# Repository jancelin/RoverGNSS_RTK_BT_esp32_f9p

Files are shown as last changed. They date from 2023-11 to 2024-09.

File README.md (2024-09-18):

> experimental code!!!

### This code allows you to connect an esp32 coupled to a Ublox F9P GNSS module on the UART port to use NTRIP clients on smartphones such as:
* [Lefebure](https://play.google.com/store/apps/details?id=com.lefebure.ntripclient) 	:white_check_mark:
* [BTGNSS](https://play.google.com/store/apps/details?id=com.clearevo.bluetooth_gnss) 	:white_check_mark:
* [SwMpas](https://play.google.com/store/apps/details?id=np.com.softwel.swmaps) 	:white_check_mark:

## Param Arduino IDE

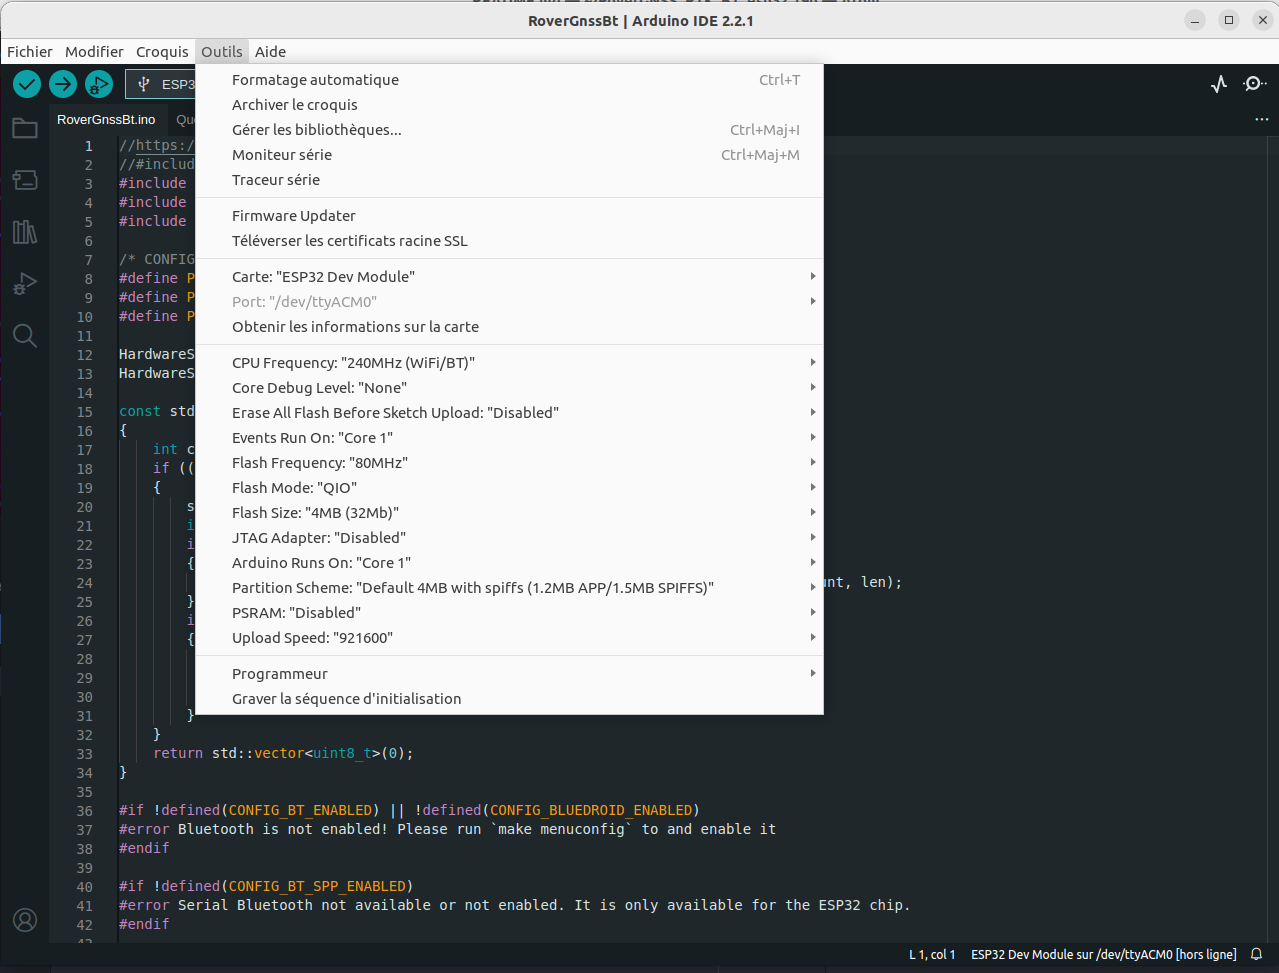
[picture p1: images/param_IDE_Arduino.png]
param


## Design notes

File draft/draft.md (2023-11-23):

# Cahier des charges - Développement et Fabrication Projet Rover GNSS

## Modules GNSS Possibles

1. **F9P Drotek Mpcie:**
   - [Lien Produit](https://store-drotek.com/923-DP0602.html)
   - [Fiche Technique](https://raw.githubusercontent.com/drotek/datasheets/master/DrotekDoc_0923%20-%20DP0602%20(mPCIe%20F9P).pdf)
   - 

2. **F9P Ardusimple Mpcie:**
   - [Lien Produit](https://www.ardusimple.com/product/simplertk2b-mpcie-zed-f9p/)
   - Connectique en évolution pour les prochains modèles, en attendant : [Guide d'intégration PCB](https://www-ardusimple-com.translate.goog/pcb-integration-guide-simplertk2b-mpcie/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)

3. **Mosaic X5 Ardusimple Mpcie:**
   - [Lien Produit](https://www.ardusimple.com/product/simplertk3b-mpcie-septentrio-mosaic/)
   - 

## Référence des Pinouts des Cartes GNSS en Mpcie

1. **F9P Mpcie Ardusimple:**
   - 36 USB_DATA-
   - 38 USB_DATA+
   - 22 RESET

2. **F9P Mpcie Drotek:**
   - 17 UART1 Tx
   - 19 UART1 Rx
   - 36 USB_DATA-
   - 38 USB_DATA+
   - 45 UART2 Tx
   - 47 UART2 Rx
   - 49 EXTINT
   - 51 TIMEPULSE

3. **Mosaic X5 Mpcie Ardusimple:**
   - 11 COM2 Rx
   - 13 COM2 Tx
   - 17 EXTINT
   - 19 TIMEPLUSE
   - 22 RESET
   - 36 USB_DATA-
   - 38 USB_DATA+
   - 45 COM3 Rx
   - 47 COM3 Tx
   - 49 COM1 Rx
   - 51 COM1 Tx

## Microcontrôleur ESP32 WROOM

- [Pinout Joy-It SBC-NodeMCU-ESP32](https://joy-it.net/files/files/Produkte/SBC-NodeMCU-ESP32/SBC-NodeMCU-ESP32-Manual-2021-06-29.pdf)

  

## Connexion ESP32 -> F9P Drotek

### Dev Actuel Transposé au Matériel Connectique Mpcie

> L'ensemble des projets est théoriquement adaptable en connexion sur les pinouts USB, mais l'accès aux autres pins est essentiel au maximum.

- **Projet "ROVER Bluetooth"** ([Lien GitHub](https://github.com/jancelin/RoverGNSS_RTK_BT_esp32_f9p))
  - 16 UART1 Rx ESP32 -> UART1 17 Tx Drotek F9P
  - 17 UART1 Tx ESP32 -> UART1 19 Rx Drotek F9P

- **Projet "PHYSALIA_MAVI"** ([Lien GitHub](https://github.com/jancelin/physalia/tree/main/buoy_mavi))
  - Connexion data en SDA/SDC, possible de l'adapter en UART (normalement):
  - 16 UART1 Rx ESP32 -> UART1 17 Tx Drotek F9P
  - 17 UART1 Tx ESP32 -> UART1 19 Rx Drotek F9P

- **F9p-ntrip-esp32** ([Lien GitHub](https://github.com/buched/F9p-ntrip-esp32))
  - 17 UART1 Rx ESP32 -> UART1 17 Tx Drotek F9P
  - 23 VSPI_MOSI ESP32 -> UART1 19 Rx Drotek F9P

...

## Possibilités

### Objectif PCB

Offrir le plus de possibilités de connexion entre l'ESP32, le récepteur GNSS, et des pins à souder. Si il n'est pas possible d'avoir une connexion directe, prévoir des pins à souder qui amènent directement au port du matériel.

### Pins Communs aux Récepteurs GNSS Mpcie

- **Pin 36**
  - USB_DATA- (Sortie - Drotek)
  - USB_DATA- (Sortie - Ardusimple MosaicX5)

- **Pin 38**
  - USB_DATA+ (Sortie - Drotek)
  - USB_DATA+ (Sortie - Ardusimple MosaicX5)

- **Pin 17**
  - Extint (Entrée et Sortie)
  - UART1 Tx (Sortie - Drotek)

- **Pin 19**
  - Timepulse (Entrée et Sortie)
  - UART1 Rx (Entrée - Drotek)
  - Timepulse (Sortie - Ardusimple MosaicX5)

- **Pin 45**
  - UART2 Tx (Sortie - Drotek)
  - COM3 Rx (Entrée - Ardusimple MosaicX5)

- **Pin 47**
  - UART2 Rx (Entrée - Drotek)
  - COM3 Tx (Sortie - Ardusimple MosaicX5)

- **Pin 49**
  - Extint (Sortie - Drotek)
  - COM1 Rx (Entrée - Ardusimple MosaicX5)

- **Pin 51**
  - Timepulse (Sortie - Drotek)
  - COM1 Tx (Sortie - Ardusimple MosaicX5)

### Connexion ESP32 -> GNSS

- **Pin 01 UART0 Tx** -> **Pin 36**
  - USB_DATA- (Entrée - Drotek)
  - USB_DATA- (Entrée - Ardusimple MosaicX5)

- **Pin 03 UART0 Rx** -> **Pin 38**
  - USB_DATA+ (Sortie - Drotek)
  - USB_DATA+ (Sortie - Ardusimple MosaicX5)

- **Pin 16 UART1 Tx** -> **Pin 45**
  - UART2 Tx (Sortie - Drotek)
  - COM3 Rx (Entrée - Ardusimple MosaicX5)

- **Pin 17 UART1 Rx** -> **Pin 47**
  - UART2 Rx (Entrée - Drotek)
  - COM3 Tx (Sortie - Ardusimple MosaicX5)
 
- **Pin 22 VSPI_MOSI Rx** -> 

### Objectifs Supplémentaires

- Rendre accessible ESP32 UART1-GNSS 45/47 + SCL/SDA en connectique à souder
- Rendre accessible alimentation 3.3V/VIN+GND en connectique à souder
- Switch pour paramétrage USB (UART0) vers ESP32 ou récepteur GNSS
- Microcontrôleur ESP32 WROOM pour Bluetooth classique
- Charge batterie connexion USB
- Batterie 2000mAh
- connecteur batterie standard 2mm
- Niveau de charge
- Interrupteur général ON/OFF
- Compact, plat, format carte de crédit
- Antenne GNSS: Connectique SMA F90 to IPEX-1 F, blindée, longueur à adapter en fonction du modèle 3D de la boîte (environ 5-10 cm)
- Exemple de montage ports data supplémentaires [Voir ici](https://www.seeedstudio.com/Grove-Shield-for-Seeeduino-XIAO-p-4621.html)
- Modèle 3D, impression
- Intégration module 4g

### Branchement

 exemple de connexion avec f9p Drotek ou mosaic x5 ardusimple AS
 
| ESP32 WROOM| FONCTION | Piste | Mpcie GNSS| FONCTION | Piste | à Souder| Commentaires |
|:---:|:---:|:---:|:---:|:---:|:-----:|:---:|:---:|
| **01**| **UART0 Tx** | ----------->| **36**| **USB_DATA-** | - |  - | |
| **03**| **UART0 Rx** | <-----------| **38**| **USB_DATA+** | - |  - | |
| **16**| **UART1 Rx** | <-----------| **45**| **UART2 Tx Drotek / COM3 Rx AS**  |<----- | **1** | |
| **17**| **UART1 Tx** | ----------->| **47**| **UART2 Rx Drotek / COM3 Tx AS**  |-----> | **2** | |
| **19**| **UART2 Rx SPI VSPI_MISC**| <-----jumper| **17**| **UART1 Tx Drotek / Extint AS** |<----- | **3** |#include <HardwareSerial.h>|
| **19**| | <-----jumper| **49**| **Extint Drotek / COM1 Rx AS** |-----> | **4** | |
| **23**| **UART2 Tx SPI VSPI_MOSI**| ----->jumper| **19**| **UART1 Rx Drotek / Timepulse AS**|-----> | **5** |#include <HardwareSerial.h>|
| **23**| | ----->jumper| **51**| **Timepulse Drotek / COM1 Tx AS** |-----> | **6** | |
| **21**| **I2C SDA** | <-----------|-------|-----------------------------------|-----> | **SDA** | |
| **22**| **I2C SCL** | <-----------|-------|-----------------------------------|-----> | **SCL** | |
|**GND**| <-------------------------| ----------> | **4** | **GND** |-----> | **GND** | |
|**3V3**| <-------------------------| ----------> | **2** | **3V3** |-----> | **3V3** | |
|**VIN**| <-------------------------| ------------|-------|-----------------------------------|-----> | **VIN** | |
|**34** | **Analogique** | ------------|-------|-----------------------------------|-----> | **D34** | |

> TODO rajouter tout SPI? https://randomnerdtutorials.com/esp32-microsd-card-arduino/

> TODO ou brancher un récepteur 4G?

### Schéma Branchement

```mermaid
flowchart LR
    03[Esp32_16] -->|UART1 Rx| 23[Mpcie_45]
    23 --> 41[*pin 1]
    04[Esp32_17] -->|UART1 Tx| 24[Mpcie_47]
    24 --> 42[*pin 2]
    05[Esp32_19] -->|UART2 Rx| 60{Jumper_1}
    60 --> 25[Mpcie_17]
    60 --> 26[Mpcie_49]
    25 --> 43[*pin 3]
    26 --> 44[*pin 4]
    06[Esp32 23] -->|UART2 Tx| 62{Jumper_2}
    62 --> 27[Mpcie_19]
    62 --> 28[Mpcie_51]
    27 --> 45[*pin 5]
    28 --> 46[*pin 6]
    07[Esp32_SDA] --> 47[*pin SDA]
    08[Esp32_SCL] --> 48[*pin_SCL]
    80{USB} -->|Data| 81{switch}
    81 -->|USB_DATA+| 22[Mpcie_38]
    81 -->|USB_DATA-| 21[Mpcie_36]
    81 -->|UART0 Tx| 01[Esp32_01]
    81 -->|UART0 Rx| 02[Esp32_03]
    100[ESP32] --> 01
    100 --> 02
    100 --> 03
    100 --> 04
    100 --> 05
    100 --> 06
    100 --> 07
    100 --> 08
    100 -->|analogique| 30[Esp32_34]
    30 --> 49[*pin D34]
```

```mermaid
flowchart LR
    80{USB} -->|Energie| 70{Alimentation}
    70 --> 82[Batterie]
    70 --> 71{5V}
    70 --> 72{GND} 
    70 --> 73{3v3}
    71 --> 11[Esp32_VIN]
    72 --> 09[Esp32_GND]
    73 --> 10[Esp32_3V3]
    72 --> 29[Mpcie_GND]
    73 --> 30[Mpcie_3V3]
    73 --> 50[*pin 3V3]
    72 --> 49[*pin GND]
    71 --> 51[*pin VIN]
```

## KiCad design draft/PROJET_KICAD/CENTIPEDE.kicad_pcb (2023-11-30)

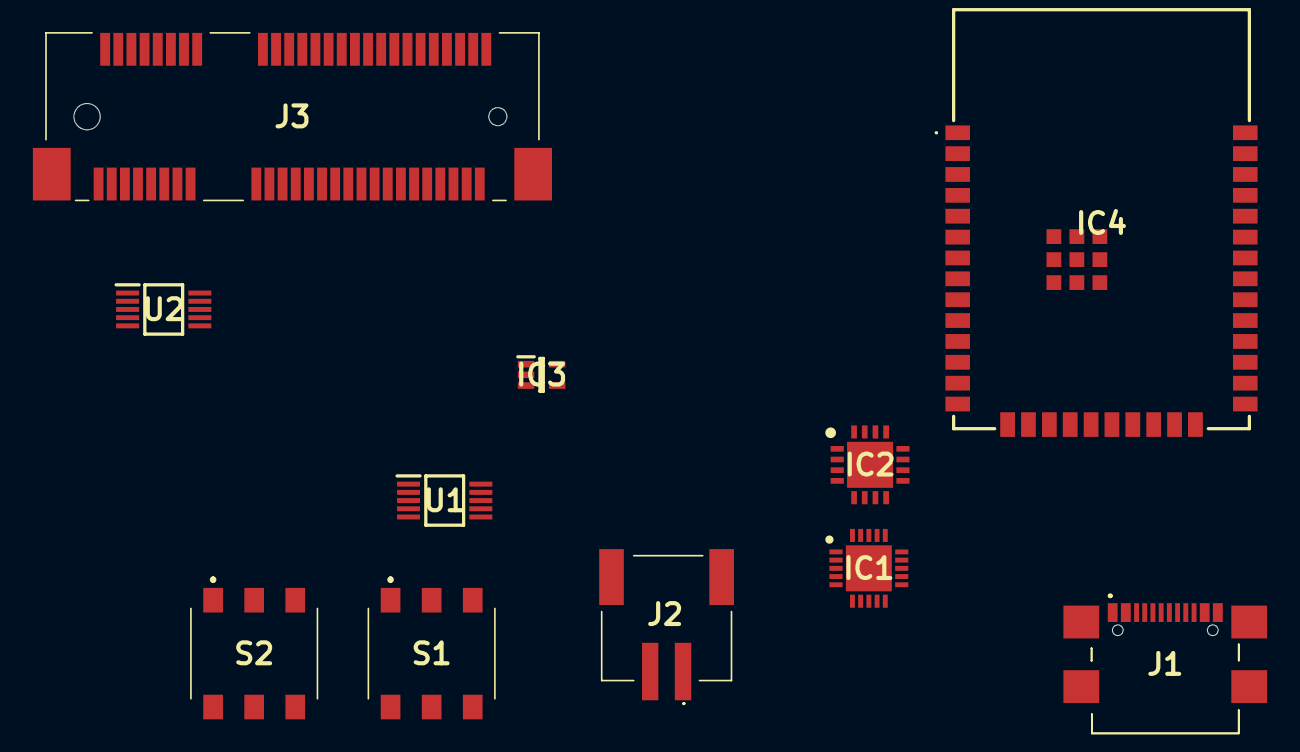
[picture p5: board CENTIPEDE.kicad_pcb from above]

Board: 2 copper layers, 11 parts (0 on the bottom side), 2 nets, no tracks yet.

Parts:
IC1: MCP73871-2CCI_ML; QFN50P400X400X100-21N-D
IC2: TPS61090RSAR; QFN65P400X400X100-17N
IC3: SC573V33RTRC; SOT65P210X110-5N
IC4: ESP32-WROOM-32E-N8; ESP32WROOM32EN8
J1: USB4110-GF-A; USB4110GFA
J2: S2B-PH-SM4-TB_LF__SN_; S2BPHSM4TBLFSN
J3: 67910-0002; 67910-5700
S1, S2: 452403012014
U1, U2: FSUSB42MUX; SOP50P490X110-10N

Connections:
5V_USB_C: J1.A4, J1.A9, J1.B4, J1.B9
GND: J1.A1, J1.A12, J1.B1, J1.B12, J1.MP1, J1.MP2, J1.MP3, J1.MP4

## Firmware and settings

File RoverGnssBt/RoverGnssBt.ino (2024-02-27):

//https://github.com/IgorKilipenko/ublox_esp_ble_uart/blob/main/src/main.cpp
//#include <Arduino.h>
#include "header.h"
#include "queue"
#include "BluetoothSerial.h"

/* CONFIG for UART1 */
#define PIN_TX 26
#define PIN_RX 27 
#define POWER_PIN 25

HardwareSerial *RTCM{&Serial1};
HardwareSerial *Receiver{&Serial2};

const std::vector<uint8_t> readReceiverData()
{
    int count = 0;
    if ((count = Receiver->available()) > 0)
    {
        std::vector<uint8_t> buffer(count);
        int len = Receiver->readBytes(buffer.data(), count);
        if (len != count)
        {
            log_e("Not all bytes read from uart, available: [%i], read: [%i]\n", count, len);
        }
        if (len > 0)
        {
            // queue_buffer.push(buffer);
            log_d("data count %d\n", buffer.size());
            return buffer;
        }
    }
    return std::vector<uint8_t>(0);
}

#if !defined(CONFIG_BT_ENABLED) || !defined(CONFIG_BLUEDROID_ENABLED)
#error Bluetooth is not enabled! Please run `make menuconfig` to and enable it
#endif

#if !defined(CONFIG_BT_SPP_ENABLED)
#error Serial Bluetooth not available or not enabled. It is only available for the ESP32 chip.
#endif

BluetoothSerial SerialBT;

std::vector<uint8_t> buffer(RX_BUFFER_SIZE * 2);
int tryCount = 0;

void receiveFnc()
{
    log_d("Received UART Data. Available For Reading = %u\n", Receiver->available());
    while (Receiver->available())
        Receiver->read(); // Discard received data.
}

void receiveErrorFnc(hardwareSerial_error_t error)
{
    log_e("UART Reception Error: ");
    bool bufferOverflow = false;
    switch (error)
    {
    case UART_BREAK_ERROR:
        log_e("UART_BREAK_ERROR\n");
        break;
    case UART_BUFFER_FULL_ERROR:
        log_e("UART_BUFFER_FULL_ERROR\n");
        bufferOverflow = true;
        break;
    case UART_FIFO_OVF_ERROR:
        log_e("UART_FIFO_OVF_ERROR\n");
        bufferOverflow = true;
        break;
    case UART_FRAME_ERROR:
        log_e("UART_FRAME_ERROR\n");
        break;
    case UART_PARITY_ERROR:
        log_e("UART_PARITY_ERROR\n");
        break;
    }
    if (bufferOverflow)
    {
        log_w("Clear buffers");
        while (Receiver->available())
            Receiver->read();
        buffer.clear();
    }
}

void onGnssReceiveCb()
{
    if (!SerialBT.hasClient())
    {
        while (Receiver->available())
            Receiver->read();
        return;
    }
    if (Receiver->available())
    {
        while (Receiver->available())
            buffer.push_back(Receiver->read());
    }
}

void onRtcmReceiveCb()
{
    if (!SerialBT.hasClient())
    {
        while (RTCM->available())
            Receiver->read();
        return;
    }
    /*const int len = RTCM->available();
    if (len)
    {
        while (RTCM->available())
            buffer.push_back(RTCM->read());
    }*/
}

void setup()
{
    Serial.begin(BAUD_SERIAL);

    // POWER_PIN : This pin controls the power supply of the MICRO PCI card
    pinMode(POWER_PIN, OUTPUT);
    digitalWrite(POWER_PIN, HIGH);

    SerialBT.begin("RoveF9pESP32_ROM"); // Bluetooth device name
    Serial.println("The device started, now you can pair it with bluetooth!");

    Receiver->setRxBufferSize(RX_BUFFER_SIZE);
    Receiver->onReceive(onGnssReceiveCb, false);
    Receiver->onReceiveError(receiveErrorFnc);
    // Receiver->setRxTimeout(1);

    Receiver->begin(115200, SERIAL_8N1, PIN_RX, PIN_TX /*, false, 20000UL, static_cast<uint8_t>(SERIAL_SIZE_RX)*/);
    // Receiver->begin(BAUND_RECEIVER, SERIAL_8N1, RXD2, TXD2 /*, false, 20000UL, static_cast<uint8_t>(SERIAL_SIZE_RX)*/);

    // delay(500);
  
    unsigned long detectedBaudRate = Receiver->baudRate();
    if (detectedBaudRate)
        log_d("Receiver uart baudrate detecyed -> [ %lu ]", detectedBaudRate);
    else
    {
        log_w("Receiver baudrate not detected");
        Receiver->begin(115200, SERIAL_8N1, PIN_RX, PIN_TX /*, false, 20000UL, SERIAL_SIZE_RX*/);
        // Receiver->begin(BAUD_SERIAL, SERIAL_8N1, RXD2, TXD2 /*, false, 20000UL, SERIAL_SIZE_RX*/);

    }

    RTCM->setRxBufferSize(RX_BUFFER_SIZE);
    RTCM->onReceive(onRtcmReceiveCb, false);
    RTCM->onReceiveError(receiveErrorFnc);

    // RTCM->begin(115200, SERIAL_8N1, 16, 17);
    // RTCM->begin(115200, SERIAL_8N1, RXD1, TXD1);
}

void loop()
{


    if (SerialBT.hasClient())
    {
        const size_t bufferSize = buffer.size();
        if (bufferSize >= RX_BUFFER_SIZE || (bufferSize > 0 && tryCount > 3))
        {
            const size_t writeCount = SerialBT.write(buffer.data(), min(bufferSize, (size_t)RX_BUFFER_SIZE * 4));
            log_d("Write %lu bytes from %lu", writeCount, bufferSize);
            int partSize = bufferSize - writeCount;
            if (partSize > 0)
            {
                log_w("WARN BT Buffer overflow = %lu, Total buffer size = %lu\n", partSize, bufferSize);
            }

            tryCount = 0;
            buffer.clear();

            if (writeCount >= RX_BUFFER_SIZE * 2)
            {
                delay(10);
                SerialBT.flush();
            }
            else
            {
                delay(1);
            }
        }
        else
        {
            if (bufferSize > 0)
            {
                tryCount++;
                SerialBT.flush();
            }
        }

        const int inLen = SerialBT.available();
        if (inLen)
        {
            uint8_t bytes[inLen];
            const size_t sizeRes = SerialBT.readBytes(bytes, inLen);
            const size_t writeCount = Receiver->write(bytes, inLen);
            if (writeCount > 0)
            {
                delay(10);
            }
            else
            {
                delay(1);
            }
        }
    }
    else
    {
        if (buffer.size() > 0)
        {
            buffer.clear();
            tryCount = 0;
        }
    }
    delay(1);
}

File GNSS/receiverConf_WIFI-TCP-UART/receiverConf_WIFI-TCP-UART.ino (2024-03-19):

/* ***************************************************************************************************/
/* Code to push to ESP to update firmware over Wifi 
/* Manage connection from U-Center to DP0602 RTK GNSS (mPCIe F9P)*/
/*
/* Author : Julien Ancelin 
/* ***************************************************************************************************/
#include <WiFi.h>
  
// debug log, set to 1 to enable
#define ENABLE_DEBUG_LOG 1
#define POWER_PIN 25

// wifi config
const char* ssid     = "SSID-NAME";
const char* password = "SSID-PSWD";
  
// ethernet config
const IPAddress local_IP(192, 168, 70, 98);
const IPAddress gateway(192, 168, 70, 99);
const IPAddress subnet(255, 255, 255, 0);
const IPAddress primaryDNS(8, 8, 8, 8);
const IPAddress secondaryDNS(8, 8, 4, 4);
  
// rs-server config
const int serverPort = 1234;
  
// rs port config
const int baudrate = 115200;
const int rs_config = SERIAL_8N1;
  
// reading buffor config
#define BUFFER_SIZE 1024
  
// global objects
WiFiServer server;
byte buff[BUFFER_SIZE];
  
void debug_log(char* str) {
#if ENABLE_DEBUG_LOG == 1
   Serial.println(str);
#endif
}
  
void setup() {

    // POWER_PIN : This pin controls the power supply of the MicroPCI
  pinMode(POWER_PIN, OUTPUT);
  digitalWrite(POWER_PIN, HIGH);

// init rs port
   Serial.begin(baudrate, rs_config);
   Serial1.begin(115200, SERIAL_8N1, 27, 26 /*, false, 20000UL, SERIAL_SIZE_RX*/);
  
// init wifi connection
if (!WiFi.config(local_IP, gateway, subnet, primaryDNS, secondaryDNS)) {
       debug_log("Failed to configure network settings");
}
   WiFi.begin(ssid, password);
while (WiFi.status() != WL_CONNECTED) {
       debug_log("connecting to WiFi network");
       delay(500);
}
  
   debug_log("connected to WiFi");
   debug_log("IP adddr: ");
   debug_log((String)WiFi.localIP());
   delay(1000);
  
//start server
   server = WiFiServer(serverPort);
   server.begin();
   delay(1000);
   debug_log("server started");
}
  
void loop() {
// wait for client
   WiFiClient client = server.available();
if (!client)
return;
  
   debug_log("client found");
while (client.connected()) {
int size = 0;
  
// read data from wifi client and send to serial1
while ((size = client.available())) {
           size = (size >= BUFFER_SIZE ? BUFFER_SIZE : size);
           client.read(buff, size);
           Serial1.write(buff, size);
           Serial1.flush();
}
  
// read data from serial1 and send to wifi client
while ((size = Serial1.available())) {
           size = (size >= BUFFER_SIZE ? BUFFER_SIZE : size);
           Serial1.readBytes(buff, size);
           client.write(buff, size);
           client.flush();
}
}
   debug_log("client disconnected");
   client.stop();
}

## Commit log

2023-01-24 adapt 2 arduino ide, modify uart1 txrx for running with pflite
    [config_f9p_310519.txt]
2023-01-24 add config for f9p UART1: RTCM3 in / NMAE output 5hz
2023-01-24 add config for IDE arduino
2023-11-30 kicad project added for pcb rtk rover v6
    [CENTIPEDE.kicad_pcb, CENTIPEDE.kicad_sch, SUPPLY_CENTIPEDE.kicad_sch]
2023-11-30 Correct errors on supply schematic
    [CENTIPEDE.kicad_sch, SUPPLY_CENTIPEDE.kicad_sch]
2024-02-29 rename files
    [CENTIPEDE.kicad_pcb, CENTIPEDE.kicad_sch, SUPPLY_CENTIPEDE.kicad_sch]
2024-02-29 param arduino ide
2024-02-29 less cable upd f9p receiver over wifi with U-center
2024-03-19 Adding POWER_PIN variable
